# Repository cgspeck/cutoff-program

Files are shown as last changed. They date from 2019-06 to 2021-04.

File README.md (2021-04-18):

# 3D Printer Power control system

This allows a Raspberry Pi running [OctoPrint](https://octoprint.org/) and the [PSU Control Plugin](https://plugins.octoprint.org/plugins/psucontrol/) to control the power supply to a 3D printer.

There is a connection for a [12V network smoke detector](https://www.aliexpress.com/item/32850855553.html?spm=a2g0s.9042311.0.0.27424c4dtptgRe). The smoke detector must be connected, and in a good state, for the power to turn on.

---

**WARNING AND DISCLAIMER**

There is no guarantee whatsoever that this unit will function as intended and there is no responsibility on my part.

Further, working with mains electricity has its own inherent risks. If you attempt this project then you assume all responsibility

---

## How it functions

Once built the Arduino brains of the circuit is connected to some GPIO pins of a Raspberry Pi running Octoprint via the level shifter component.

When power is first connected a startup phase runs for four seconds, during which the alert buzzer & signal will be tested.

After startup, a two-way centre-off toggle switch determines whether the printer:

- is powered on by manual demand (up)
- is off (center)
- is powered on demand by a connected Raspberry Pi (down)

A second toggle switch determines whether the extraction fan:

- is powered on demand by a connected Raspberry Pi (up)
- is off (center)
- is slaved to the printer's power status (down)

The extraction fan will be powered unless the printer is powered.

If the smoke detector is triggered, or gets disconnected:

- power to the printer is cut off
- power to the extraction fan is cut off
- the buzzer is sounded constantly
- an alert signal is sent to the Raspberry Pi

The only way to recover the system once triggered is via the reset button.

You should supply power to the power control system, Pi, printer, extraction fan and all via Saftey Switch/RCBO/GFCI breaker in order to protect yourself and also render the system incapable of automatically starting up in the event of loss, and resumption, of mains electrical supply/

## Development

### Development Prerequisites

- [Arduino IDE >= 1.8.4](https://www.arduino.cc/en/Main/Software)

- [Arduino-Makefile](https://github.com/sudar/Arduino-Makefile)

- [direnv](https://direnv.net/) for managing arduino & avr library and tool locations if the defaults don't work

The version of Arduino in the Ubuntu repository is ancient and will not work. Consider using `scripts/install-deps.sh` which uses [umake](https://github.com/ubuntu/ubuntu-make) to install up to date Arduino environment.

### Handy Hints

Building, uploading and starting the monitor: `make`

To quit the monitor (gnu screen): `CTRL + A`, `:quit`.

VS Code Intelligence not working? Check [this post](https://github.com/Microsoft/vscode-arduino/issues/438#issuecomment-345362087).

### Typical paths

The default paths in `./Makefile` are for Ubuntu.

Typical paths for OSX, with Arduino-Makefile installed via Homebrew, are (`.envrc`):

```bash
export ARDUINO_DIR=/Applications/Arduino.app/Contents/Java
export ARDMK_DIR=/usr/local/opt/arduino-mk
export AVR_TOOLS_DIR=/Applications/Arduino.app/Contents/Java/hardware/tools/avr
export AVRDUDE=/Applications/Arduino.app/Contents/Java/hardware/tools/avr/bin/avrdude
export AVRDUDE_CONF=/Applications/Arduino.app/Contents/Java/hardware/tools/avr/etc/avrdude.conf
```

### As-built Pins

| RPI (GPIO/BCM) | Interface Circuit |
| --- | --- |
| 26 (brown) | Fan Power (inverted, low = on, only works if printer is powered) |
| 23 (green) | Printer Power (inverted, low = on) |
| 24 (yellow) | alarm state? |
| GND (orange) | GND |
| 25 (red) | Printer State (high = on) |

## License

Arduino 3d printer cut off program
Copyright (C) 2019 Christopher Speck

This program is free software: you can redistribute it and/or modify
it under the terms of the GNU General Public License as published by
the Free Software Foundation, either version 3 of the License, or
(at your option) any later version.

This program is distributed in the hope that it will be useful,
but WITHOUT ANY WARRANTY; without even the implied warranty of
MERCHANTABILITY or FITNESS FOR A PARTICULAR PURPOSE. See the
GNU General Public License for more details.

You should have received a copy of the GNU General Public License
along with this program. If not, see <https://www.gnu.org/licenses/>.

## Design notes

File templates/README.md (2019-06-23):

# Templates

## Front Template

Required punchouts:

* ac pilot light
* led power light
* green button (action)
* red button (reset)
* printer three way mode switch
* fan three way mode switch

## Rear Template

Required punchouts:

* IEC power inlet
* AU Power outlet (printer)
* AU Power outlet (fan)

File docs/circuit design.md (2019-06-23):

# Circuit Design Considerations

## RPI

Select following ports/pins:

* GPIO23 OUTPUT: Rpi Printer Power Demand
* GPIO24 INPUT (INTERNAL PULLDOWN): Arduino Printer Power Status
* GPIO25 INPUT (INTERNAL PULLDOWN): Arduino Alarm Triggered (should this be flipped?)
* GND between 24 & 23: To ground on protoboard

https://raspberrypi.stackexchange.com/questions/83610/gpio-pinout-orientation-raspberypi-zero-w

## Arduino

Select following pins/ports:

* 2 INPUT_PULLUP: detector ok signal
* A1 INPUT_PULLUP: two way toggle switch - PI printer power demand or manual power demand
* 4 INPUT_PULLUP: two way toggle switch - fan slaved to printer or PI fan power demand
* 5: reserved, n/c
* A4 OUTPUT: buzzer & pi alarm line
* 6 OUTPUT: relay for printer
* 8 OUTPUT: relay for fan
* GND: protoboard ground
* 3v3: to logic level shifter LV side
* 5v:
  * to logic level shifter HV side
  * to detector common line

## 12v switch mode supply

* GND to protoboard ground
* +12VDC to:
    * smoke detector
    * to relays

## Logic level shifter

References:
https://www.sparkfun.com/products/retired/11978
https://forum.arduino.cc/index.php?topic=381795.0
https://www.sparkfun.com/products/retired/8745
https://www.jaycar.com.au/arduino-compatible-logic-level-converter-module/p/XC4486
https://www.jaycar.com.au/medias/sys_master/images/9229265928222/XC4486-manualMain.jpg

Connections see below

## Momentary Pushbutton (green, softbutton)

Not connected. Reserved for pin 5.

## Momentary Pushbutton (red, reset)

Connect via header strip
switch between GND & RST

## Detector

Connect via header strip
10k pulldown resistor between 2 and GND
Common to 5v

## Printer mode switch

Connect via header strip
Common to A1
10k pull-down resistor between common and ground
Pole 1 to Logic level shifter TX0
Pole 2 to 5v

## Fan mode switch

Connect via header strip
Common to D4
10k pull-down resistor between common and ground
Pole 1 to Logic level shifter TX0
Pole 2 to 5v

## Arduino -> Transistor / Relay / Logic shifter

Select 560R between digital output and Base
Collector connected to Relay
Emitter to ground
Diode in reverse between Relay poles (negative band towards +12VDC)
Select 1N4007 diodes
Relay attached via screw terminals
Logic shifter connected between digital out & resistor to tell Pi when the printer is actually on

## Logic shifter -> Arduino

Connect TX/RX directly to pins
Ground to protoboard
5v to Arduino
3v3 to Arduino

Goes high when Pi is disconnected, so pull downs required upstream of TXOs

## Logic shifter -> Pi

Connect TXI/RXO directly to GPIO via screw terminals
Ground to protoboard via screw terminals

## Buzzer - 12v

Connect via a transistor as per relays

## Arduino power light

https://www.jaycar.com.au/chrome-bezel-with-5mm-red-led/p/SL2610
2V, 15mA
Select 220R resistor inline with LED (drop voltage to 1.7v, limit to 15mA)
Connect via header strip

## Relays

https://www.digikey.com.au/product-detail/en/te-connectivity-potter-brumfield-relays/T9AP1D52-12/T9AP1D52-12-ND/287569
https://www.te.com/commerce/DocumentDelivery/DDEController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

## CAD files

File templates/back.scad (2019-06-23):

use <lib.scad>;
thickness = 1.5;
base_width = 150;
base_height = 72;

number_of_penetrations = 3;

spacing = base_width / (number_of_penetrations + 1);

echo("Spacing ", spacing, "mm");

iec_in = 9.5;
ac_out_printer = 31;
ac_out_fan = ac_out_printer;
data_rpi_and_firealarm = 15;

holes = [
    iec_in,
    ac_out_printer,
    ac_out_printer,
    // data_rpi_and_firealarm
];

projection() difference() {
    cube([base_width, base_height, thickness]);

    translate([
        spacing * 2,
        base_height / 2,
        0
    ]) located_cylinder(holes[1] / 2, thickness * 2);

    translate([
        spacing * 3.3,
        base_height / 2,
        0
    ]) located_cylinder(holes[2] / 2, thickness * 2);

    translate([
    spacing * 1 + (22.5 / 2),
    base_height / 2 - (50 / 2),
    4
    ]) rotate([-90, 0, 90]) iec_socket();

    translate([22.5 / 2, base_height / 2, 0]) located_cylinder(9.5 / 2, thickness * 2);
}

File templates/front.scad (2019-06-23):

use <lib.scad>;
thickness = 1.5;
base_width = 150;
base_height = 72;


number_of_penetrations = 6;

spacing = base_width / (number_of_penetrations + 1);

echo("Spacing ", spacing, "mm");

ac_pilot_light = 9.5;
led_pilot_light = 8;
red_button = 12;
green_button = red_button;
printer_mode_switch = 6;
fan_mode_switch = printer_mode_switch;

holes = [
    ac_pilot_light,
    led_pilot_light,
    red_button,
    green_button,
    printer_mode_switch,
    fan_mode_switch
];

projection() difference() {
    cube([base_width, base_height, thickness]);

    for(i=[1:1:6]) {
        translate([
            spacing * i,
            base_height / 2,
            0
        ]) located_cylinder(holes[i - 1] / 2, thickness * 2);
    }
}

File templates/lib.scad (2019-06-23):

module located_cylinder(radius, height) {
    translate([0, 0, -1]) {
        difference() {
            cylinder(height, r=radius);
            translate([0, 0, -1]) cylinder(height + 2, r=0.5);
        }
    }
}

module iec_socket(thickness = 4.5, width = 50) {
    rect_width = 31.5;
    edge_width = (width - rect_width) / 2;   
    height = 22.5;

    cutout_base_width = 27;
    cutout_top_width = 16;
    cutout_top_width_offset = (cutout_base_width - cutout_top_width) / 2; 

    cutout_base_height = 14;
    cutout_height = 19;

    screw_hole_center_from_rectangle = 5;

    translate([edge_width, 0, 0]) {
        difference() {
            union(){
                cube([rect_width, thickness, height]);

                translate([0, thickness, 0]) {
                    rotate([90, 0, 0]) linear_extrude(thickness) polygon([
                        [0, 0],
                        [-edge_width, height / 2],
                        [0, height]
                    ]);

                    rotate([90, 0, 0]) linear_extrude(thickness) polygon([
                        [rect_width, height],
                        [rect_width + edge_width, height / 2],
                        [rect_width, 0]
                    ]);

                }    
            }
            translate([-screw_hole_center_from_rectangle, 2, height / 2]) rotate([90, 0, 0]) cylinder(h=thickness + 2, r=1.5, center=true);
            
            translate([rect_width + screw_hole_center_from_rectangle, 2, height / 2]) rotate([90, 0, 0]) cylinder(h=thickness + 2, r=1.5, center=true);
            
            translate([(rect_width - cutout_base_width) / 2, thickness + 1, (height - cutout_height) / 2]) rotate([90, 0, 0]) linear_extrude(thickness + 2) polygon([
                [0, 0],
                [cutout_base_width, 0],
                [cutout_base_width, cutout_base_height],
                [cutout_base_width - cutout_top_width_offset, cutout_height],
                [cutout_top_width_offset, cutout_height],
                [0, cutout_base_height],
            ]);
        }
    }
}

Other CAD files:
templates/Meanwell RS-15-12.scad

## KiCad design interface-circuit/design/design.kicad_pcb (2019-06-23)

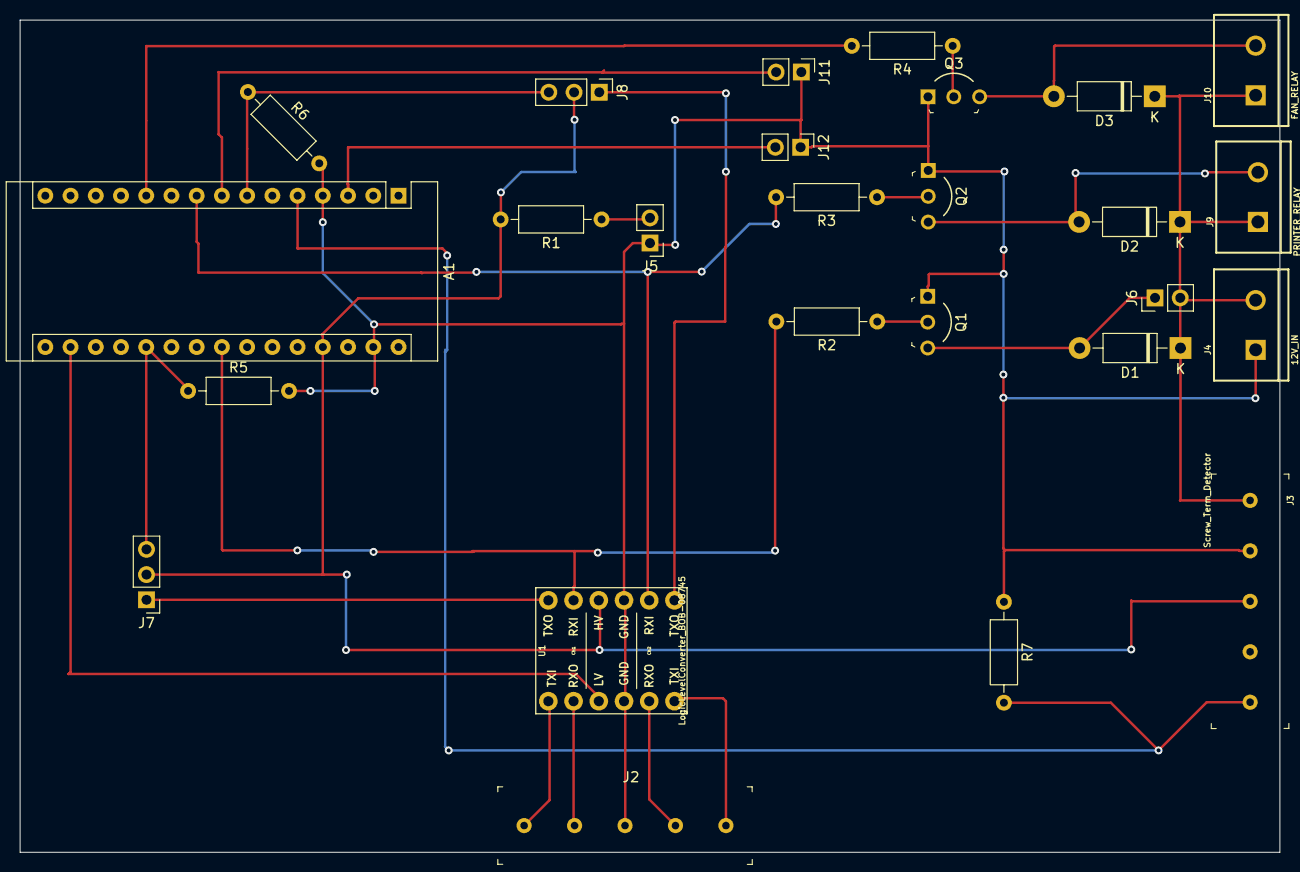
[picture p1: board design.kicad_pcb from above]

Board: 2 copper layers, 126.8 x 83.8 mm, 26 parts (0 on the bottom side), 25 nets.

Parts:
A1: Arduino_Nano_v3.x; Arduino_Nano
D1, D2, D3: 1N4007; D_DO-41_SOD81_P10.16mm_Horizontal
J2: Screw_Term_RPi; Term_Block_1x5_P5.08mm
J3: Screw_Term_Detector; Term_Block_1x5_P5.08mm
J4: 12V_IN; SCREWTERMINAL-5MM-2
J5: Conn_Pwr_LED; PinHeader_1x02_P2.54mm_Vertical
J6: Conn_Piezo; PinHeader_1x02_P2.54mm_Vertical
J7: Conn_Printer_Mode; PinHeader_1x03_P2.54mm_Vertical
J8: Conn_Fan_Mode; PinHeader_1x03_P2.54mm_Vertical
J9: PRINTER_RELAY; SCREWTERMINAL-5MM-2
J10: FAN_RELAY; SCREWTERMINAL-5MM-2
J11: Conn_Switch; PinHeader_1x02_P2.54mm_Vertical
J12: Conn_Reset; PinHeader_1x02_P2.54mm_Vertical
Q1, Q2, Q3: 2N3904-AP; TO-92-3_Formed_Leads
R1: 220R; R_Axial_DIN0207_L6.3mm_D2.5mm_P10.16mm_Horizontal
R2, R3, R4: 560R; R_Axial_DIN0207_L6.3mm_D2.5mm_P10.16mm_Horizontal
R5, R6, R7: 10R; R_Axial_DIN0207_L6.3mm_D2.5mm_P10.16mm_Horizontal
U1: LogicLevelConverter_BOB-08745; LOGIC_LEVEL_CONVERTER_BOB-8745

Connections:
+3V3: A1.17, U1.6
+5V: A1.27, J3.3, J7.2, J8.2, R1.2, U1.5
+12V: D1.1, D2.1, D3.1, J3.1, J4.2, J6.2, J9.1, J10.1
/-PIEZO: D1.2, J6.1, Q1.3
/D7_PRINTER_RELAY: A1.9, R3.2, U1.2
/D8_FAN_RELAY: A1.11, R4.2
/DETECTOR_SIGNAL: A1.5, J3.5, R7.2
/HV_AlarmTriggered: A1.23, R2.2, U1.1
/HV_FanPowerDemand: J8.1, U1.12
/HV_PrinterPowerDemand: J7.1, U1.11
/LV_AlarmTriggered: J2.2, U1.9
/LV_FanPowerDemand: J2.5, U1.4
/LV_PrinterPowerDemand: J2.1, U1.3
/LV_PrinterPowerStatus: J2.4, U1.10
/RESET: A1.3, J12.2
/SOFT_SWITCH: A1.8, J11.2
/SW_FAN_RELAY: A1.7, J8.3, R6.1
/SW_PRINTER_RELAY: A1.20, J7.3, R5.1
GND: A1.4, A1.29, J2.3, J3.2, J4.1, J5.1, J11.1, J12.1, Q1.1, Q2.1, Q3.1, R5.2, R6.2, R7.1, U1.7, U1.8
unnamed: D2.2, J9.2, Q2.3
unnamed: D3.2, J10.2, Q3.3
unnamed: J5.2, R1.1
unnamed: Q1.2, R2.1
unnamed: Q2.2, R3.1
unnamed: Q3.2, R4.1

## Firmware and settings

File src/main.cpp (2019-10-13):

/*
Arduino 3d printer cut off program
Copyright (C) 2019 Christopher Speck

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
You should have received a copy of the GNU General Public License
along with this program.  If not, see <https://www.gnu.org/licenses/>.
*/
#include <Arduino.h>

// INPUT SIGNALS
#define PIN_IN_DETECTOR_SIGNAL 2
/*
 * no need to define a reset input just bring RESET to low by closing with GND
 * RESET pin has an internal pullup resistor
*/
#define PIN_IN_PI_PWR_DEMAND_PRINTER A1
#define PIN_IN_PI_PWR_DEMAND_FAN 4

/*
An inline RCD physically prevents entire system from starting up following a powercut
without intervention.

The circuit also includes a momentary push button grounding the reset pin.

This pin is reserved for a future use.
*/
#define PIN_IN_PUSHBUTTON 5

// OUTPUT SIGNALS
// combines buzzer and pi notification
#define PIN_OUT_ALERT A4

#define PIN_RELAY_PRINTER 6
#define PIN_RELAY_FAN 8

#define FLASH_INTERVAL 500
#define STARTUP_INTERVAL 3000

#define SERIAL_REPORT_INTERVAL 1000

// alarm has to be on for this much time before power will be cut
#define TRIGGER_DELAY 2000

// globals
bool startingUp = true;
bool firstCheck = true;
bool alertFlashState = false;
bool detectorTriggered = false;

bool previousPiPrinterPwrDemand = false;
bool previousPiFanPwrDemand = false;
bool fanDemandOverridden = false;
bool actualPrinterPwrState = false;
bool actualFanPwrState = false;

unsigned long previousFlashMillis = 0;
unsigned long previousSerialReportMillis = 0;

bool inIncident = false;
unsigned long incidentStart = 0;

// allow alarm to be truned off remotely by
// cycling the power demand pin alertAckCount times
bool alertLastObs = false;
int alertObsCount = 0;
int alertAckCount = 2;

// function prototypes
void setupOutputPin(int pinNumber, int initialState = LOW);

// functions
void setupOutputPin(int pinNumber, int initialState)
{
  pinMode(pinNumber, OUTPUT);
  digitalWrite(pinNumber, initialState);
}

void setup()
{
  pinMode(PIN_IN_DETECTOR_SIGNAL, INPUT);
  pinMode(PIN_IN_PI_PWR_DEMAND_PRINTER, INPUT_PULLUP);
  pinMode(PIN_IN_PI_PWR_DEMAND_FAN, INPUT_PULLUP);
  setupOutputPin(PIN_OUT_ALERT);
  setupOutputPin(PIN_RELAY_PRINTER);
  setupOutputPin(PIN_RELAY_FAN);
  Serial.begin(9600);
}

void doSerialReport(unsigned long currentMillis)
{
  if ((unsigned long)(currentMillis - previousSerialReportMillis) >= SERIAL_REPORT_INTERVAL)
  {
    Serial.print("Time:");
    Serial.println(currentMillis);

    String statusMsg = ((startingUp) ? "Starting Up" : ((detectorTriggered) ? "Detector triggered" : "Idle"));

    Serial.print("Status:");
    Serial.println(statusMsg);

    Serial.print("Printer power state:");
    Serial.println(actualPrinterPwrState);

    Serial.print("Fan power state:");
    Serial.println(actualFanPwrState);

    Serial.print("Printer power demand:");
    Serial.println(previousPiPrinterPwrDemand);

    Serial.print("Fan power demand:");
    Serial.println(previousPiFanPwrDemand);

    Serial.print("Fan power override:");
    Serial.println(fanDemandOverridden);

    previousSerialReportMillis = currentMillis;
  }
}

void loop()
{
  unsigned long currentMillis = millis();
  fanDemandOverridden = false;

  if (startingUp)
  {
    // flash the alert light
    if ((unsigned long)(currentMillis - previousFlashMillis) >= (int)FLASH_INTERVAL)
    {
      alertFlashState = !alertFlashState;
      // combines buzzer and pi notification
      digitalWrite(PIN_OUT_ALERT, alertFlashState);
      previousFlashMillis = currentMillis;

      if (currentMillis >= STARTUP_INTERVAL)
      {
        startingUp = false;
      }
    }

    doSerialReport(currentMillis);
    return;
  }

  bool piPrinterPwrDemand = (digitalRead(PIN_IN_PI_PWR_DEMAND_PRINTER) == LOW);

  if (detectorTriggered)
  {
    doSerialReport(currentMillis);
    //
    // check if the incident has been acknowledged by the power demand
    // being cycled by alertAckCount
    //
    if (alertLastObs==false && piPrinterPwrDemand) {
      alertObsCount ++;
    }
    if (alertLastObs==true && ! piPrinterPwrDemand) {
      if (alertObsCount >= alertAckCount) {
        digitalWrite(PIN_OUT_ALERT, LOW);
      }
    }
    alertLastObs=piPrinterPwrDemand;
    return;
  }

  if (firstCheck)
  {
    digitalWrite(PIN_OUT_ALERT, LOW);
    firstCheck = false;
  }

  if (digitalRead(PIN_IN_DETECTOR_SIGNAL) == LOW)
  {
    if (inIncident && ((unsigned long)(currentMillis - incidentStart) >= (int)TRIGGER_DELAY)) {
      digitalWrite(PIN_RELAY_PRINTER, LOW);
      digitalWrite(PIN_RELAY_FAN, LOW);
      digitalWrite(PIN_OUT_ALERT, HIGH);
      detectorTriggered = true;
      actualPrinterPwrState = false;
      actualFanPwrState = false;
      doSerialReport(currentMillis);
      return;
    } else {
      inIncident = true;
      incidentStart = currentMillis;
    }
  } else {
    inIncident = false;
  }

  if (piPrinterPwrDemand != previousPiPrinterPwrDemand)
  {
    previousPiPrinterPwrDemand = piPrinterPwrDemand;
    actualPrinterPwrState = previousPiPrinterPwrDemand;
    digitalWrite(PIN_RELAY_PRINTER, actualPrinterPwrState);
  }

  bool piFanPwrDemand = (digitalRead(PIN_IN_PI_PWR_DEMAND_FAN) == LOW);

  previousPiFanPwrDemand = piFanPwrDemand;

  if (piFanPwrDemand) {
    if (!piPrinterPwrDemand) {
      // no power to fan if power to printer is off
      piFanPwrDemand = false;
      fanDemandOverridden = true;
    }
  }

  if (actualFanPwrState != piFanPwrDemand) {
    actualFanPwrState = piFanPwrDemand;
    digitalWrite(PIN_RELAY_FAN, piFanPwrDemand);
  }

  doSerialReport(currentMillis);
}

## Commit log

2018-09-21 Initial commit with firmware for Arduino
2019-04-07 prototype code for breadboard
2019-04-12 Trying out Arduino-Makefile project
2019-04-18 Switch to a Nano
2019-04-24 Adding a push button that must be pressed to start the system
2019-04-25 Fleshing out circuit specifications
2019-06-23 Kicad design (#3)
    [Meanwell RS-15-12.scad, back.scad, design.kicad_pcb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]
2019-10-02 This didn't appear to do anything (#4)
    [main.cpp]
2019-10-02 Insert a 1.5 second delay between smoke alarm going off and power being cut (#5)
2019-10-13 Allow alarm to be turned off remotely by cycling power domand pin
2021-04-18 Add an SVG of circuit so I can refer to it without needing Kicad
